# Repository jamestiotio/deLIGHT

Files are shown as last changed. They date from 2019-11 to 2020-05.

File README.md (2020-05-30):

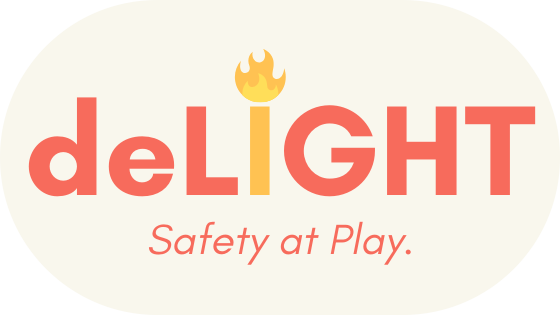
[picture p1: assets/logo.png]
# 
**SUTD 2019 03.007 Introduction to Design Project**

_Theme: At Play 2.0_

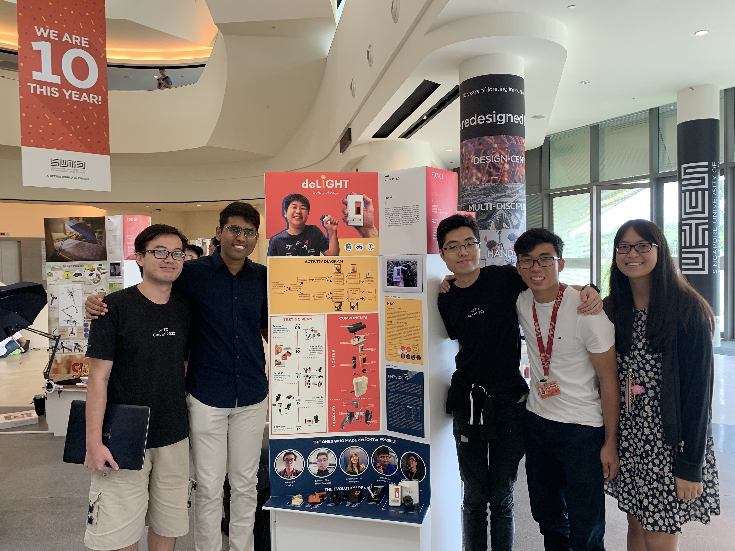
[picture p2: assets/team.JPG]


19F07 Group 1 Team Members:
- [James Raphael Tiovalen](https://github.com/jamestiotio) (Team Coordinator & Project Manager)
- [Velusamy Sathiakumar Ragul Balaji](https://github.com/ragulbalaji) (Software Specialist & Technical Advisor)
- [Kenneth Chin Choon Hean](https://github.com/UrFriendKen) (Chief Mechanical & Electrical Engineer)
- [Mun Jern Wei Ivan](https://github.com/monkeychimpanzee) (Project Advisor & Lead Actor)
- [Sharmayne Lim Zhiyu](https://github.com/sl194) (Creative Director & Lead Artist)

Since GitHub limits single file size to 100 MB, the project video could not be uploaded/committed to GitHub. Instead, it is available on YouTube [here](https://youtu.be/HanKIdMyvy4).

## Problem Statement

Unsupervised children playing with lighters leads to grave consequences (supported by statistics of burns and deaths worldwide). Additionally, lighters which have run out of fuel are rendered useless in situations whereby lighter refills and charging points are unavailable. Our solution prevents children from activating the lighter when they come into contact with it as it has a fingerprint lock that only registered fingerprints are able to unlock. Also, when our lighter has run out of fuel, there is an option to recharge it by winding it. At the same time, our lighter allows children to have fun by playing video games on it or winding it.

## Product Description

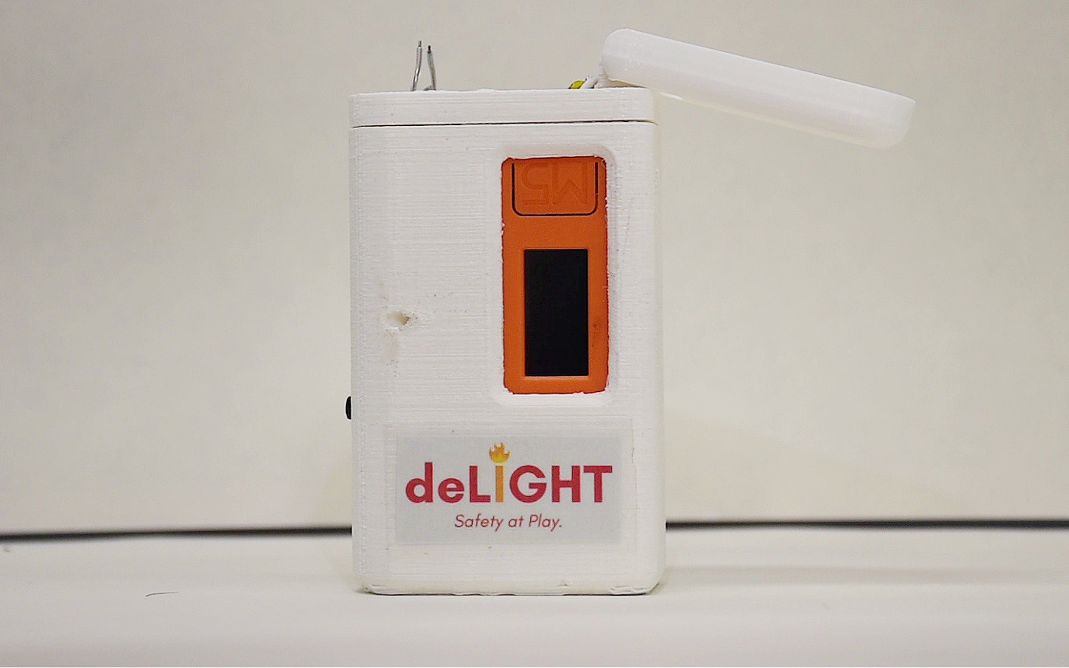
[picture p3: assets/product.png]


The key highlighted features of our product are:

1. **Fingerprint Sensor**

This capacitive sensor allows us to capture, collect, store and sense fingerprint patterns. This feature is used to restrict access to the lighter.

2. **M5Stick-C**

This is the big boi that does most of the work. This mini IoT core device is based on the ESP32 chip and is equipped with common features, such as Wi-Fi, Bluetooth, LCD Display, LED, Button, Buzzer, IR Transmitter, Battery and Six-Axis MPU. This allows us to do some cool, unconventional integrations of certain systems that only involve light processing power to the lighter. Such an example would be the simple **Game Feature** that would run when an unauthorised fingerprint is detected. Note that the fingerprint detection callback still runs asynchronously while the game is running. The game that we currently implement is a simple low-level adaptation of Flappy Bird with balloons as obstacles. Of course, given more time and effort, more intricate games could potentially be written (although care needs to be taken regarding memory usage and the fact that it is very troublesome to write the graphics and physics drivers from scratch). This module also handles the **Wi-Fi Feature** connectivity and processing.

3. **Plasma Lighter**

Instead of using gas fuel, we utilise a more sustainable, reusable and rechargeable energy source such as a battery. A possible case illustration of its sustainability is that this would reduce the amount of plastic unintentionally consumed by animals like birds. The battery could be charged either through the USB port or by using the hand crank.

4. **Speaker**

Our product is also equipped with a piezoelectric speaker that provides auditory feedback to convey messages or to reinforce certain actions that the user had done.

5. **Hand Crank**

The lighter is equipped with a detachable hand crank that could be wound to provide more energy through its charging circuit.

## Design Requirements & Choices

1. Our product needs to be tightly linked to a specific object taken from a preselected list of suggested, well-designed objects. Our object of focus was the Zippo lighter.

2. We only had a budget of SGD$500 and thus, we sourced for cheap PLA material to construct the lighter's casing and we also sourced for relatively cheaper alternatives of fingerprint sensors and IoT processors.

3. We chose a winding method instead of a shaking mechanism since, by performing some rough preliminary estimations and calculations, we found that winding would provide more energy to the battery (or the device) than shaking.

4. Limitations of our product are mainly centered around energy efficiency, ease of use and ergonomics:

    - The concern over the energy efficiency of the hand crank is relevant to our project. Conversion from mechanical to electrical energy is usually not very efficient since a lot of energy is wasted as heat and sound.

    - Another plausible and reasonable concern is that users would find it a hassle to have to unlock a mere lighter with their fingerprint every time they want to use it. Thus, we tried to implement the Wi-Fi verification method as well as a proof of concept in order to make it slightly easier for users to use the lighter.

    - Finally, the overall size of the lighter is larger than the usual lighter. This is due to the slightly bulky structure of the M5Stick-C. On the other hand, the M5Stick-C is jam-packed with plenty of features in such a tight space that the temptation to include everything in such an Apple-like compact design is quite high.
    
5. Our design focus is on rapid prototyping, as well as iterative development and feature testing. Therefore, our code currently should only be used during development and not in a production-level environment.

## Future Work

Several improvements (and new ideas) that could be implemented include:

1. Better reliability/control/safety in terms of precision and accuracy of the magnitude of the electrical current discharge (so as to not overload any components), as well as the overall reliability of the whole electrical circuit. Short-circuits and accidental contacts with live wires/batteries were encountered quite often during testing, which should not be the case.

2. Integration with Siri. M5Stick-C has a microphone that could support this integration. Apple's HAP might be needed for this.

3. An additional security feature in terms of Morse code tapping password detection (?).

4. (Old Idea) 3D Capacitor Pattern Lock (setup of three perpendicular plates).

## Acknowledgements

Credits to [Prof. Arlindo Silva](https://epd.sutd.edu.sg/people/faculty/arlindo-silva) and [Prof. Daniel Joseph Whittaker](https://asd.sutd.edu.sg/people/faculty/daniel-joseph-whittaker) as our cohort instructors who guided us through every single step of this journey!

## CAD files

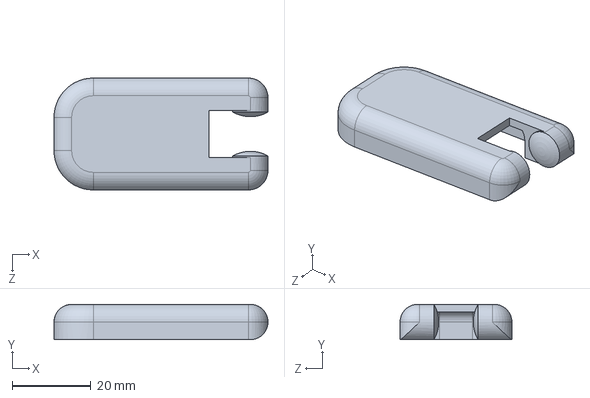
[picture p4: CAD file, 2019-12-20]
Prototypes/CAD/Lid.SLDPRT
54.5 x 9.00 x 28.5 mm

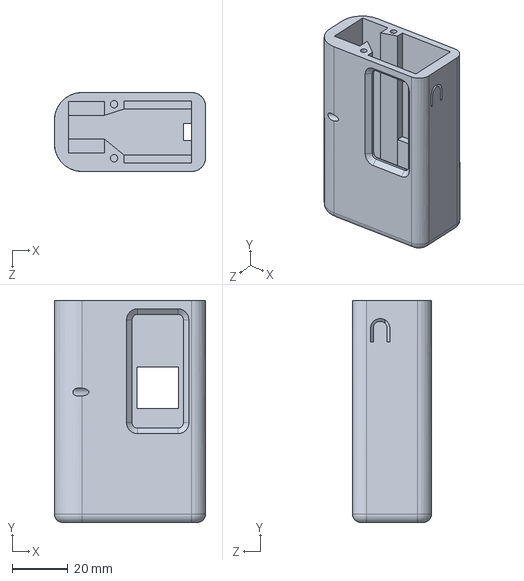
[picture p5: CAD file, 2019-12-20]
Prototypes/CAD/Casing.SLDPRT
54.5 x 80.0 x 28.5 mm

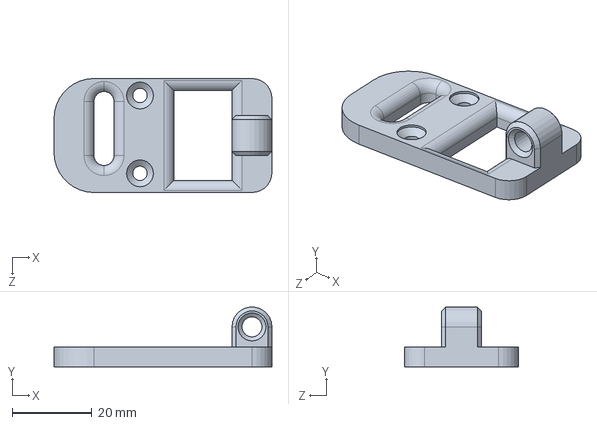
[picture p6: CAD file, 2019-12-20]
Prototypes/CAD/Interface.SLDPRT
54.5 x 15.0 x 28.5 mm

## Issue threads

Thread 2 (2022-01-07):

peripheral.py returns errors when commanding

aofek, 2022-01-07:
Dear James
using esp32 with your "peripheral.py" returns a message as in the pictures, while the "basic_ble.py" activates the advertising, connects and communicates with "serial bluetooth terminal" app on the phone.

I am searching for "notify a close-by ble device" which means using the esp32 periodically on scan/advertise mode without connection , preferably with rssi signal level upon detection.

could you help me , please, understand what is the nature of the error, so I can switch between the 2 modes with time sharing?
``
the esp32 dev board is a basic board, nothing fancy, "Lolin `D32"`

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

---code---- basic_ble.py

# boot section
import esp
import esp32
import micropython
from micropython import const
import machine
from machine import Pin,I2C,SoftI2C,ADC,Timer
import utime
import time
from time import sleep_ms
import struct
import random
import network
import ubluetooth
from ubluetooth import BLE
adcamp1=ADC(Pin(32))
adcamp2=ADC(Pin(33))
adcamp3=ADC(Pin(34))
adcbat=ADC(Pin(35))
led=Pin(2,Pin.OUT) # pin 2 in devkit1
machine.freq(240000000)

#------------------------------------------

class BLE():            # BLE class
    def __init__(self, name):
        self.name = name
        self.ble = ubluetooth.BLE()
        self.ble.active(True)
        
        self.led=led
        self.timer1 = Timer(0)
        self.timer2 = Timer(1)
        
        self.disconnected()
        self.ble.irq(self.ble_irq)
        self.register()
        self.advertiser()

    def connected(self):
        self.timer1.deinit()
        self.timer2.deinit()

    def disconnected(self):
        self.timer1.init(period=1000, mode=Timer.PERIODIC, callback=lambda t: self.led(1))
        sleep_ms(10)
        self.timer2.init(period=1000, mode=Timer.PERIODIC, callback=lambda t: self.led(0))

    def ble_irq(self, event, data):
        if event == 1:
            '''Central disconnected'''
            self.connected()
            self.led(1)
            
        elif event == 2:
            '''Central disconnected'''
            self.advertiser()
            self.disconnected()

        elif event == 3:
            '''New message received'''    
            buffer = self.ble.gatts_read(self.rx)
            message = buffer.decode('UTF-8').strip()
            print(message)    
            if message == 'led':
                led.value(not led.value())
                print('led', led.value())
                ble.send('led' + str(led.value()))
            if message=='hmc':
                magdat=adc_loop()
                ble.send(str(magdat))

    def register(self):
        # Nordic UART Service (NUS)
        NUS_UUID = '6E400001-B5A3-F393-E0A9-E50E24DCCA9E'
        RX_UUID = '6E400002-B5A3-F393-E0A9-E50E24DCCA9E'
        TX_UUID = '6E400003-B5A3-F393-E0A9-E50E24DCCA9E'
    
        BLE_NUS = ubluetooth.UUID(NUS_UUID)
        BLE_RX = (ubluetooth.UUID(RX_UUID), ubluetooth.FLAG_WRITE)
        BLE_TX = (ubluetooth.UUID(TX_UUID), ubluetooth.FLAG_NOTIFY)
    
        BLE_UART = (BLE_NUS, (BLE_TX, BLE_RX))
        SERVICES = (BLE_UART, )
        ((self.tx, self.rx,), ) = self.ble.gatts_register_services(SERVICES)

    def send(self, data):
        utime.sleep(0.001)
        self.ble.gatts_notify(0, self.tx, data + '\n')

    def advertiser(self):
        name = bytes(self.name, 'UTF-8')
        self.ble.gap_advertise(100, bytearray('\x02\x01\x02') + bytearray((len(name) + 1, 0x09)) + name)

#----------------------------------------
def adc_loop():
    amp1 =adcamp1.read()
    amp1=amp1+1000
    amp2 =adcamp2.read()
    amp2=amp2+1000
    amp3 =adcamp3.read()
    amp3=amp3+1000
    bat =adcbat.read()
    bat=bat+1000
    magdat=[amp1]+[amp2]+[amp3]+[bat]
    print(magdat)
    return magdat
#--------------------------------------------------------

if __name__ == '__main__':
    ble = BLE('hmc001')

jamestiotio, 2022-01-07:
Hi @aofek,

After seeing your error, it seems that you typed _'advertise'_ instead of _advertise_ (without the quotation marks). The quotation marks in the script are to indicate that it is a string. However, when you enter the command in the console, it should be without quotation marks. Can you attempt this fix and check whether this solves the problem?

aofek, 2022-01-07:
Hi James
Thank you
It looks ok now
I am still in learning stage, but when in advertise, it reacts to a connect attempt from the phone.
When in scan, there is no error but it doesn't react to advertising ble around it, so i  must dig in deeper.
Thank you very much James

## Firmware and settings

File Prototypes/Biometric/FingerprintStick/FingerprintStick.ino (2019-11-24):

/* MODIFIED TO PERFORM FASTER ON OUR SPECIFIC HARDWARE
   YOUR MILEAGE MAY VARY.
   -> ragulbalaji Nov 2019
*/

#include <M5StickC.h>
#include "finger.h"
#include <ESP32Servo.h>

#define LID_CLOSE 160
#define LID_OPEN 50

uint8_t userNum; //User number
FingerPrint FP_M;
Servo lockservo;

void clearScreen() {
  M5.Lcd.fillRect(0, 0, 400, 300, BLACK);
  M5.Lcd.setCursor(0, 0);
  M5.Lcd.setTextSize(2);
  M5.Lcd.setTextColor(WHITE);
  userNum = FP_M.fpm_getUserNum();
  //M5.Lcd.print("userNum:");
  //M5.Lcd.println(userNum);
}

void reeconnect() {
  Serial2.end();
  delay(100);
  Serial2.begin(19200, SERIAL_8N1, 33, 32);
}

void openLid(int pos){ // Do not use
  lockservo.attach(26);
  
  int val = 0;
  if(pos == 0) val = 150;
  else if(pos == 1) val = 70;
  
  lockservo.write(val);
  delay(3000);
  lockservo.detach();
}

void setup() {
  M5.begin();
  //Serial.begin(115200);
  Serial2.begin(19200, SERIAL_8N1, 33, 32);
  
  lockservo.attach(26);
  lockservo.write(LID_CLOSE);
  
  M5.Lcd.setRotation(3);
  clearScreen();
  M5.Lcd.setCursor(0, 0);
  M5.Lcd.setTextSize(3);
  M5.Lcd.setTextColor(RED);
  M5.Lcd.println("deLight BioLock!");

  M5.Lcd.setTextSize(1);
  M5.Lcd.setTextColor(WHITE);

  userNum = FP_M.fpm_getUserNum();
  //M5.Lcd.setCursor(0, 50);
  //M5.Lcd.print("userNum:");
  //M5.Lcd.println(userNum);
}

void loop() {
  uint8_t res1;

  if (M5.BtnA.wasPressed()) { // Big Button for Matching
    clearScreen();
    M5.Lcd.setTextColor(RED);
    M5.Lcd.println("deTouchID");
    M5.Lcd.setTextColor(WHITE);
    M5.Lcd.println("Place Finger");
    delay(1000); // Wait for user! Observation from trail run.
    M5.Lcd.println("Scanning...");
    res1 = FP_M.fpm_compareFinger();
    if (res1 == ACK_SUCCESS) {
      M5.Lcd.setTextColor(GREEN);
      M5.Lcd.println("Success!"); // Time to unlock

      lockservo.write(LID_OPEN);
      
      clearScreen();
      M5.Lcd.setTextColor(RED);
      M5.Lcd.println("Press Button to Close Lid.");

      do{
        M5.update();
        delay(10);
      }while(!M5.BtnA.wasPressed());
      
      lockservo.write(LID_CLOSE);

      M5.Lcd.println("\n<3 <3 <3");
    } else if (res1 == ACK_NOUSER) {
      M5.Lcd.println("Try Again :(");
    } else if (res1 == ACK_TIMEOUT) {
      M5.Lcd.println("Try Again :(");
      reeconnect();
    }
  } else if (M5.BtnB.wasPressed()) { // Side Button for Enrollment
    clearScreen();
    M5.Lcd.setTextColor(ORANGE);
    M5.Lcd.println("Enrol Finger!");
    M5.Lcd.setTextColor(WHITE);
    M5.Lcd.println("Place Finger");
    delay(1000); // Wait for user! Observation from trail run.
    M5.Lcd.println("Scanning...");

    userNum = FP_M.fpm_getUserNum();
    res1 = FP_M.fpm_addUser(userNum, 1);
    if (res1 == ACK_SUCCESS) {
      M5.Lcd.println("Success!");
      userNum++;
    } else if (res1 == ACK_FAIL) {
      M5.Lcd.println("Try Again :(");
      reeconnect();
    }
    else if (res1 == ACK_FULL) {
      M5.Lcd.println("Full");
    }
    else {
      M5.Lcd.println("Try Again :(");
      reeconnect();
    }

  }

  M5.update();
}

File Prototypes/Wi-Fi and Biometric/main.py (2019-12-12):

# DELIGHT BIOMETRIC UPY
# RAGULBALAJI 2019

from m5stack import lcd, buttonA, buttonB
from random import randint, getrandbits
from time import sleep_ms
from machine import Pin, PWM, reset
import json

def readConfig():
	config = json.load(open('lighter.json'))
	return config
	
def writeConfig(config): # Use responsibly
	cfile = open('lighter.json','w')
	json.dump(config, cfile)
	cfile.close()

TONE_DELIGHT = [(1174, 250), (1479, 250), (1760, 250), (2349, 500)]
TONE_DENY = [(1760, 100), (1, 50), (1760, 400)]

def clrscrn(rot=1):
	lcd.setRotation(rot)
	lcd.clear()
	lcd.font(lcd.FONT_DejaVu24)
	lcd.setTextColor(lcd.WHITE)
	lcd.setCursor(0,0)


spkr = PWM(Pin(26), freq = 1)
spkr.duty(50)
def note(freq, ms, duty=50):
	spkr.duty(duty)
	spkr.freq(freq)
	sleep_ms(ms)

def tone(tonearr):
	for n in tonearr:
		note(n[0],n[1])
	spkr.freq(1) # almost silent!


clrscrn()
lcd.setTextColor(lcd.RED)
lcd.print("deLIGHTer\nv2.3-fut2d\n")
sleep_ms(100)
tone(TONE_DELIGHT)
sleep_ms(500)


GAME_RUNNING = False
def game_start():
	lcd.font(lcd.FONT_DejaVu18)
	GAME_RUNNING = True
	HEALTH = 10
	bird = [80,20,0,0,15] # y,x,vy,vx,r
	blns = [[80,-10,0,-1,15,lcd.BLUE],[40,-10,0.2,-0.5,10,lcd.GREEN]] # y,x,vy,vx,r,color
	GRAV = -1
	lastbtn = False
	while GAME_RUNNING:
		if HEALTH < 1: break
		if buttonA.isPressed() and not lastbtn: bird[2] += 15
		lastbtn = buttonA.isPressed()
		bird[2] += GRAV
		bird[2] *= 0.9
		bird[0] += bird[2]
		bird[0] = min(max(bird[4], bird[0]), 160-bird[4])
		lcd.clear()
		lcd.fillCircle(int(bird[0]), bird[1], bird[4], lcd.RED)
		lcd.fillCircle(int(bird[0])+6, bird[1]+2, 3, lcd.WHITE)
		lcd.fillCircle(int(bird[0])+6, bird[1]+10, 3, lcd.WHITE)
		lcd.fillCircle(int(bird[0])+6, bird[1]+2, 1, lcd.BLACK)
		lcd.fillCircle(int(bird[0])+6, bird[1]+10, 1, lcd.BLACK)
		lcd.fillTriangle(int(bird[0])-5, bird[1]+13, int(bird[0])-10, bird[1]+3, int(bird[0]), bird[1]+3, lcd.YELLOW)
		for b in blns:
			if b[1] < -b[4]:
				b[1] = 80+b[4]
				b[0] = randint(20,140)
				b[2] = (randint(0,10)-5)/5.0
				b[3] = -randint(5,10)/5.0
				b[4] = randint(5,15)
				b[5] = getrandbits(24)
			b[0] += b[2]
			b[1] += b[3]
			if((b[0]-bird[0])**2 + (b[1]-bird[1])**2 < (bird[4]+b[4])**2):
				HEALTH -= 1
				b[1] = -100
				tone([(440, 100)])
			lcd.line(int(b[0]),int(b[1]),int(b[0])-(4*b[4]),int(b[1]),lcd.WHITE)
			lcd.fillCircle(int(b[0]),int(b[1]),b[4],b[5])
		lcd.print(str(HEALTH)+" <3",140,0,lcd.WHITE,rotate=90)
		sleep_ms(30)
	
	lcd.setTextColor(lcd.WHITE)
	lcd.text(40,0,"GAME")
	lcd.text(20,0,"OVER")
	sleep_ms(700)
	tone(TONE_DENY)
	reset()

from _finger import Finger
finger = Finger()
IGNORE_FINGER = False
def fingerOKCb(user_id, access):
	global IGNORE_FINGER
	if IGNORE_FINGER: return
	GAME_RUNNING = False
	clrscrn()
	lcd.print("Welcome\nUser #"+str(user_id))
	tone(TONE_DELIGHT)
	sleep_ms(1000)
	mainScrn()
def fingerDENYCb():
	global IGNORE_FINGER
	if IGNORE_FINGER: return
	GAME_RUNNING = False
	clrscrn()
	lcd.print("Unknown  :(\nFinger")
	tone(TONE_DENY)
	sleep_ms(1000)
	clrscrn()
	lcd.setTextColor(lcd.MAGENTA)
	lcd.print("Hold button\nto skip\nthe game")
	sleep_ms(2000)
	if buttonA.isPressed(): mainScrn()
	else: game_start()
finger.readFingerCb(callback=fingerOKCb)
finger.getUnknownCb(callback=fingerDENYCb)

def enrolCb():
	global IGNORE_FINGER
	IGNORE_FINGER = True
	clrscrn()
	lcd.setTextColor(lcd.RED)
	lcd.print("Counting\nRegistered\nUsers")
	finger.uart.read()
	finger.uart.write(b'\xf5\t\x00\x00\x00\x00\t\xf5')
	sleep_ms(50)
	pkt = finger.uart.read(8)
	while len(pkt) != 8: pkt = finger.uart.read(8) 
	print(pkt)
	if pkt[0] != 0xf5 or pkt[1] != 0x09:
		clrscrn()
		tone(TONE_DENY)
		lcd.print("TRY AGAIN\n:(")
		sleep_ms(1000)
		mainScrn()
	usrid = pkt[3]
	clrscrn()
	lcd.setTextColor(lcd.GREEN)
	lcd.print("Enrol #"+str(usrid)+"\n")
	lcd.setTextColor(lcd.WHITE)
	lcd.print("Place Finger\non Sensor")
	finger.addUser(usrid+1, 1)
	while not finger.state.startswith("Add user success"):
		print(finger.state)
		sleep_ms(200)
	clrscrn()
	lcd.setTextColor(lcd.GREEN)
	lcd.print("Enrol Finger\n\nSUCCESS")
	IGNORE_FINGER = False
	sleep_ms(500)
	mainScrn()
buttonB.wasReleased(callback=enrolCb)

def mainScrn():
	clrscrn()
	lcd.setTextColor(lcd.RED)
	lcd.print("deLIGHTer\n")
	lcd.setTextColor(lcd.WHITE)
	lcd.print("Scan Finger to Unlock")
mainScrn()

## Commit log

2019-11-19 Initial example driver code for FPC1020A
2019-11-19 Working code for das Stück
    - Fixed Pinmapping
    - Increased performance
    [FingerprintStick.ino, finger.cpp]
2019-11-20 Simple Servo Stuff!
2019-12-03 Add Wi-Fi & Bluetooth detection code
    Main focus is Wi-Fi feature since Bluetooth detector is not working yet
    [peripheral.py, wireless.py]
2019-12-04 Implement servo control for Wi-Fi script
2019-12-10 Add minor fixes & graph script
    [peripheral.py, wireless.py]
2019-12-20 Add CAD files
    Courtesy of Kenneth
    [Casing.SLDPRT, Interface.SLDPRT, Lid.SLDPRT]
